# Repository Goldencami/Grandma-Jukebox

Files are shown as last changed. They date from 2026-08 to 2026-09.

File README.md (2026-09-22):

# Grandma-Jukebox
Jukebox to play songs for grandma.

The micro SD card (32GB) contains two folders named `canciones` and `himnos` in which their corresponding mp3 files are located.

> WARNING: Do **NOT** use GPIO19 or GPIO20 on this board. These GPIOs are internally connected to the USB-OTG and causes the USB no being detected by the computer. IF you accidentally upload a sketch and used those pins, you can upload an empty sketch using USB-UART and the communication with USB-OTG will work again.

> WARNING: Do NOT use GPIO2 for buttons or any other digital I/O. It is an ESP32-S3 strapping pin sampled at boot — depending on its state at power-on, it can prevent the board from booting correctly.

In development, use the USB-UART to upload code. The final version will use the charging cable to connect to USB-OTG.

https://github.com/user-attachments/assets/e78aba78-86dd-4827-824b-220895683b4c

## Commands
### Idle Screen (BMO Face)
- **Yellow Button**:  Go to the Music Type Selection screen.
- **Red Button**: Hold for 3 seconds to go to the Configuration screen.

### Music Type Selection Screen
*(selecting between "Canciones" and "Himnos Biblicos")*
- **White Button**: Toggles between the two playlist options.
- **Red Button**: Goes back to Idle Screen.
- **Green Button**: CONFIRMS — loads and plays the selected playlist, then goes to the Now Playing screen.

### Now Playing Screen
- **Green Button**: Plays/pauses the current song.
- **White Button**: Plays next song.
- **Yellow Button**: Plays previous song.
- **Red Button**: Stops the music and goes back to Idle Screen.

### Configuration Screen
*(setting date, then time — one field at a time: month → day → year, then hour → minute → AM/PM)*
- **White Button**: Increases the value of the currently selected field.
- **Yellow Button**: Decreases the value of the currently selected field.
- **Green Button**: Confirms the current field and moves to the next one. On the last field of date/time, it also saves the value and advances to the next step (date → time → back to Idle).
- **Red Button**: Cancels and goes back to Idle Screen.

## Components
- ESP32-S3 WROOM: Dual-core 32-bit microprocessor up to 240 MHz, 16 MB Flash, 16 MB PSRAM
- 3.2" 240x320 SPI TFT Display — ST7789 driver chip (confirmed; not ILI9341 despite some markings/assumptions — see Display Driver section below)
- DS3231 RTC
- MAX98357A I2S
- 3525 4ohm 3W-2.0port
- TF Micro SD Card Module with an onboard 3.3V voltage regulator circuit
- 32GB Sandisk Ultra Micro SD card
- 4 x push buttons

## Display Driver — IMPORTANT
This panel's actual controller is ST7789, not ILI9341. Use the `Adafruit_ST7789` library (via "Adafruit ST7735 and ST7789 Library" in Library Manager), not `TFT_eSPI` and not `Adafruit_ILI9341`.

**Why not TFT_eSPI**: `TFT_eSPI` crashes with a `Guru Meditation Error: StoreProhibited` (`EXCVADDR: 0x00000010`) immediately on `tft.init()`, on this exact hardware. This was confirmed reproducible across two different ESP32-S3 boards, multiple ESP32 Arduino core versions (3.2.x and 2.0.17), both ILI9341 and ST7789 driver settings, both RGB/BGR color order settings, and using the library's own unmodified stock example sketch. Root cause was never conclusively identified — suspected ESP-IDF 5.x SPI/DMA internals incompatibility — but it is reliably reproducible, so this library should be avoided for this project.

**Why not Adafruit_ILI9341**: Works partially (boots, draws, colors correctable via a manual R/B channel swap) but the addressable drawing window doesn't match the physical glass — roughly 1/5 of the right edge of the screen is not usable. This confirms the controller is not actually ILI9341.

**Use hardware SPI, not the simple constructor**: The plain `Adafruit_ST7789(CS, DC, MOSI, SCLK, RST)` constructor falls back to software SPI on ESP32, which is slow enough to make `loop()` unresponsive. Use the hardware-SPI constructor (an explicit `SPIClass` bound to a free SPI bus) instead, and call `setSPISpeed()` so the higher clock actually takes effect.

Confirmed working setup (`Adafruit_ST7789`):
```cpp
#include <Adafruit_ST7789.h>

SPIClass tftSPI(FSPI);
Adafruit_ST7789 tft = Adafruit_ST7789(&tftSPI, TFT_CS, TFT_DC, TFT_RST);

tftSPI.begin(TFT_SCLK, -1, TFT_MOSI, TFT_CS); // hardware SPI bus, no MISO needed
tft.init(240, 320);         // native resolution, required
tft.setSPISpeed(20000000);  // only takes effect with hardware SPI
tft.invertDisplay(false);   // REQUIRED — this panel needs inversion off;
                             // library defaults to inverted (ST77XX_INVON),
                             // which shows colors wrong (e.g. white as black)
tft.setRotation(1);         // landscape: width=320, height=240
```

If you ever swap in a genuinely different physical panel, re-verify the driver chip and re-test `invertDisplay(true)` vs `false` and color order before assuming this config still applies.

## Enable PSRAM in the IDE
This project enables PSRAM.

In Arduino IDE:
- Tools → PSRAM and set it to "OPI PSRAM"
- Tools → Flash Size: "16 MB (128Mb)".
- Tools → Partition Scheme: "16M Flash (2MB APP/12.5MB FATFS)".

> These are the PSRAM, Flash size and Partition Scheme values for the ESP32 that is being used.
>
> TODO: confirm and document *why* PSRAM is required (e.g. instability/crash without it) — the sketch doesn't call `ps_malloc`/`ps_calloc` directly, so if this was needed for a specific crash or buffer, note it here for future reference.

## Pinouts with ESP32


> TFT and the SD card are sharing the same SPI buses (MOSI, SCK)
### SPI TFT Screen
| SPI TFT | ESP32 |
|---|---|
| `VCC` | `3.3V` |
| `GND` | `GND` |
| `CS` | `GPIO15` |
| `RESET` | `GPIO8` |
| `DC` | `GPIO4` |
| `SDI (MOSI)` | `GPIO11` |
| `SCK` | `GPIO12` |
| `LED` | `3.3V` |

### SD CARD MODULE
| SD Card | ESP32 |
|---|---|
| `GND` | `GND` |
| `VCC` | `VIN` |
| `MISO` | `GPIO40` |
| `MOSI` | `GPIO41` |
| `SLK` | `GPIO39` |
| `CS` | `GPIO10` |

### DS3231 RTC
| DS3231 RTC | ESP32 |
|---|---|
| `GND` | `GND` |
| `VCC` | `VIN` |
| `SDA` | `GPIO21` |
| `SCL` | `GPIO47` |

### MAX98357 I2S
| MAX98357 I2S | ESP32 |
|---|---|
| `VIN` | `VIN` |
| `GND` | `GND` |
| `LRC` | `GPIO13` |
| `BCLK` | `GPIO14` |
| `DIN` | `GPIO9` |

### BUTTONS
| BUTTONS | ESP32 |
|---|---|
| `YELLOW` | `GPIO16` |
| `WHITE` | `GPIO17` |
| `RED` | `GPIO38` |
| `GREEN` | `GPIO1` |



## Credits
The arms and legs are from the [BMO model](https://www.printables.com/model/1582055-bmo-from-adventure-time-local-ai-agent-project) by brenpoly, licensed under [CC BY-NC 4.0](http://creativecommons.org/licenses/by-nc/4.0/). They were scaled to 1.5x to fit BMO's body. No other parts of that model were used.

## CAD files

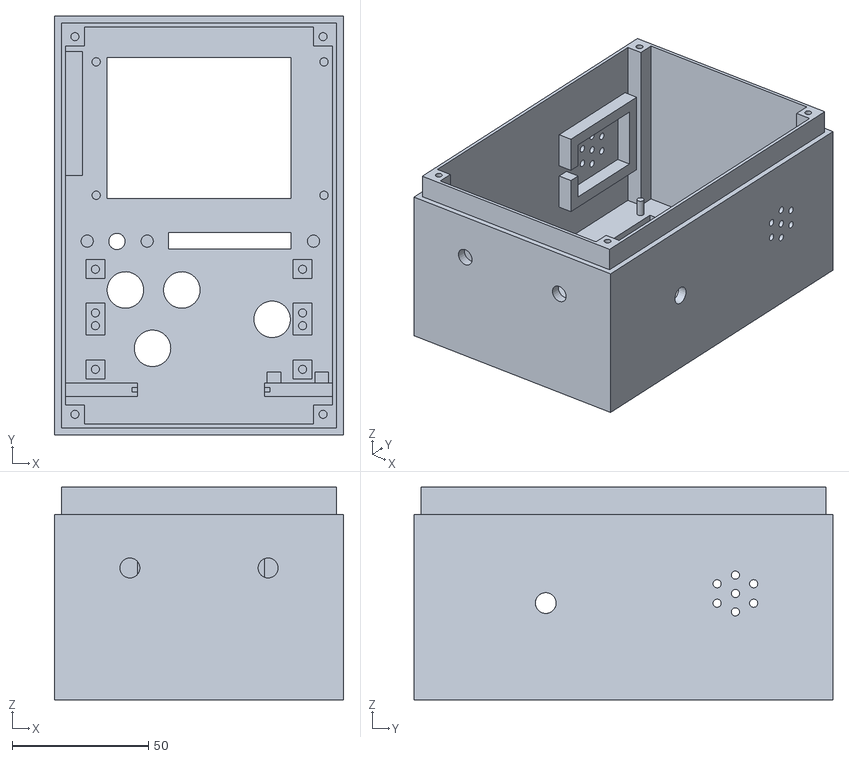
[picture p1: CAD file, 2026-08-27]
print_files/BMO_Front.stl
106.0 x 153.5 x 78.0

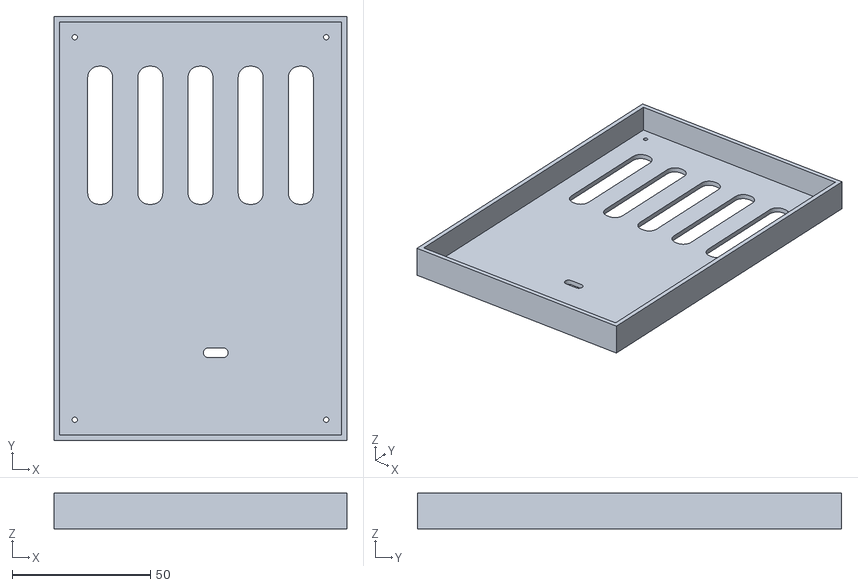
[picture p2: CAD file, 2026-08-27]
print_files/BMO_Back.stl
106.0 x 153.5 x 13.0

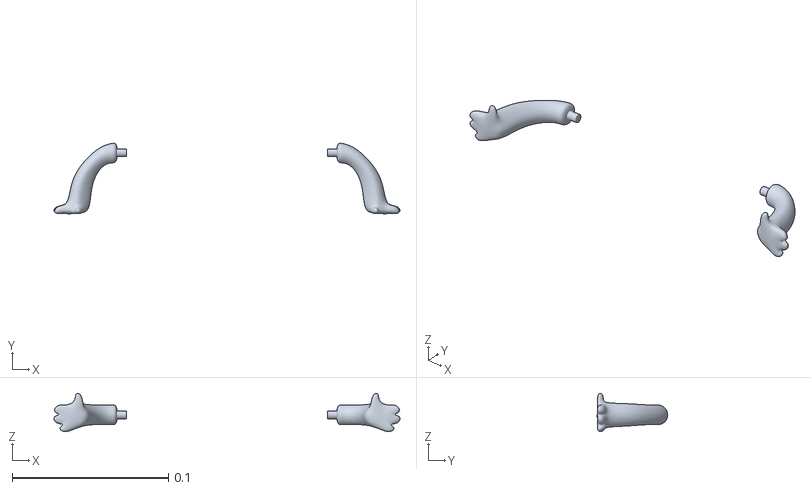
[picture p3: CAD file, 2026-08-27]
print_files/Arms_BMO.stl
0.221 x 0.0451 x 0.0245

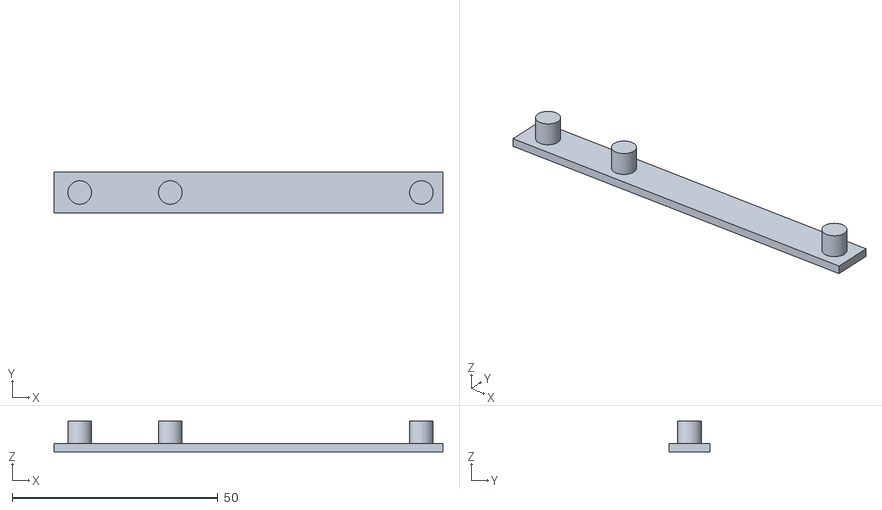
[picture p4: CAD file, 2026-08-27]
print_files/BMO_Disk.stl
94.5 x 10.0 x 7.50

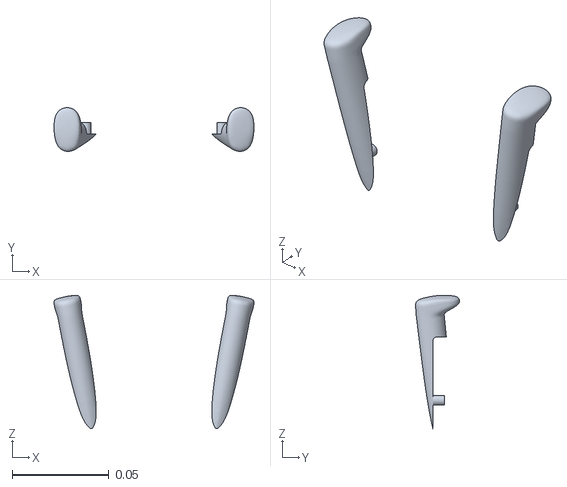
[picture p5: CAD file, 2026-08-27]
print_files/Legs_BMO.stl
0.103 x 0.0226 x 0.0689

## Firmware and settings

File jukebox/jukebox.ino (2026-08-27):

#include <SPI.h>
#include <SD.h>
#include <Adafruit_GFX.h>
#include <Adafruit_ST7789.h>
#include <Wire.h>
#include <RTClib.h>
#include <AudioFileSourceSD.h>
#include <AudioGeneratorMP3.h>
#include <AudioOutputI2S.h>
#include "esp_task_wdt.h"
#include "esp_log.h"
#include <Fonts/FreeSansBold12pt7b.h> 

#define YELLOW_BTN 16
#define WHITE_BTN 17
#define RED_BTN 38
#define GREEN_BTN 1

#define I2S_LRC  13
#define I2S_BCLK 14
#define I2S_DOUT 9

#define RTC_SDA 21
#define RTC_SCL 47

#define SD_SCK   39
#define SD_MISO  40
#define SD_MOSI  41
#define SD_CS    10

#define TFT_CS   15
#define TFT_DC    4
#define TFT_RST   8
#define TFT_MOSI 11
#define TFT_SCLK 12

// TIME VARIABLES
unsigned int debounceDelayYellow = 500;
unsigned long lastYellowDebounce = millis();
byte yellowBtnState = LOW;

unsigned int debounceDelayWhite = 500;
unsigned long lastWhiteDebounce = millis();
byte whiteBtnState = LOW;

unsigned int debounceDelayRed = 500;
unsigned long lastRedDebounce = millis();
byte redBtnState = LOW;

unsigned int debounceDelayGreen = 500;
unsigned long lastGreenDebounce = millis();
byte greenBtnState = LOW;

unsigned int RTCdelay = 500;
unsigned long lastRTCdelay = millis();

// MAX98357 I2S VARIABLES
String musicFiles[50];
int fileCount = 0;
int currentSong = 0;

// AUDIO OBJECTS (ESP8266Audio — runs on Core 0 via audioTask)
AudioGeneratorMP3 *mp3       = nullptr;
AudioFileSourceSD *audioSrc  = nullptr;
AudioOutputI2S    *audioOut  = nullptr;

// Shared state between loop() on Core 1 and audioTask on Core 0.
// Protected by audioMutex to avoid race conditions.
volatile bool audioShouldPlay = false;   // Core 1 sets true to start a song
volatile bool audioShouldStop = false;   // Core 1 sets true to stop mid-song
volatile bool audioIsPlaying  = false;   // Core 0 sets true while decoding
volatile bool audioPaused     = false;   // Core 1 toggles to pause/resume
volatile int  audioTrackIndex = 0;       // which track to play
SemaphoreHandle_t audioMutex;
TaskHandle_t audioTaskHandle = nullptr;
volatile bool manualStop = false;

// RTC VARIABLES
RTC_DS3231 rtc;
String previousTime = "-1";
String dateArr[3]; // [month, day, year]
String hoursArr[3]; // [hour, minute, AM/PM]
String tempDateArr[3];
String tempHourArr[3];
bool isSetDateDone = false;
bool isSetHourDone = false;

int lastDateIdx = -1;
int lastTimeIdx = -1;

// Convert month number to Spanish month name
const char* months[] = {"", "Enero", "Febrero", "Marzo", "Abril", "Mayo", "Junio", "Julio", "Agosto", "Septiembre", "Octubre", "Noviembre", "Diciembre"};
int monthIdx = 0;

// SD CARD VARIABLES
SPIClass sdSPI(HSPI);   // plain object, not a pointer - no TFT in this sketch to order against

// TFT VARIABLES —> using hardware SPI constructor so setSPISpeed() actually works.
// The simple Adafruit_ST7789(CS, DC, MOSI, SCLK, RST) constructor uses software
// SPI internally on ESP32, which is extremely slow and makes loop() unresponsive.
SPIClass tftSPI(FSPI);
Adafruit_ST7789 tft = Adafruit_ST7789(&tftSPI, TFT_CS, TFT_DC, TFT_RST);

// STATE MACHINE VARIABLES
enum State {
  IDLE,
  SELECTION,
  PLAY,
  CONFIGS
};

State state = IDLE;

bool isIdleScreenDisplayed = false;
bool isMusicTypeDisplayed = false;
bool isConfigScreenDisplayed = false;

// BMO FUNCTIONS
uint16_t bmoGreen;

void drawSmile(int cx, int cy, int r) {
  for (int a = 20; a <= 160; a++) {
    float rad = a * DEG_TO_RAD;

    int x = cx + r * cos(rad);
    int y = cy + r * sin(rad);

    tft.fillCircle(x, y, 2, ST77XX_BLACK);
  }
}

void BMOidleFace() {
  int w = tft.width();
  int h = tft.height();

  // background
  tft.fillScreen(bmoGreen);
  previousTime = "-1";   // force RTC to redraw on next tick — fillScreen wiped it

  // eye settings
  int eyeR = 7;
  int eyeY = h * 0.35;

  tft.fillCircle(w * 0.3, eyeY, eyeR, ST77XX_BLACK);
  tft.fillCircle(w * 0.7, eyeY, eyeR, ST77XX_BLACK);

  // smile :)
  drawSmile(w / 2, h * 0.43, 40);
}

void drawArrow(int width, int y) {
  int x = 20 + width + 5;

  tft.fillTriangle(
    x, y - 8,
    x + 10, y - 15,
    x + 10, y + 2,
    ST77XX_BLACK
  );
}

void eraseArrow(int width, int y) {
  int x = 20 + width + 5; 

  tft.fillTriangle(
    x, y - 8,
    x + 10, y - 15,
    x + 10, y + 2,
    bmoGreen
  );
}

void drawDownArrow(int width, int y) {
  int x = 20 + width + 5;

  tft.fillTriangle(
    x,      y - 10,  // top-left of base
    x + 10, y - 10,  // top-right of base
    x + 5,  y,       // bottom tip
    ST77XX_BLACK
  );
}

void eraseDownArrow(int width, int y) {
  int x = 20 + width + 5;

  tft.fillTriangle(
    x,      y - 10,  // top-left of base
    x + 10, y - 10,  // top-right of base
    x + 5,  y,       // bottom tip
    bmoGreen
  );
}

// Wraps `text` onto a second line if it's too wide to fit within `maxWidth`
// pixels (measured using the TFT's current font). Breaks at the last space
// that still fits on line 1. Returns 1 or 2 (the number of lines used).
int wrapTextTwoLines(const String &text, int maxWidth, String &line1, String &line2) {
  int16_t x1, y1;
  uint16_t w, h;

  tft.getTextBounds(text, 0, 0, &x1, &y1, &w, &h);
  if (w <= maxWidth) {
    line1 = text;
    line2 = "";
    return 1;
  }

  // Walk through spaces, keeping the furthest break point that still fits
  int breakIdx = -1;
  int searchFrom = 0;
  while (true) {
    int spaceIdx = text.indexOf(' ', searchFrom);
    if (spaceIdx == -1) break;

    tft.getTextBounds(text.substring(0, spaceIdx), 0, 0, &x1, &y1, &w, &h);
    if (w <= maxWidth) {
      breakIdx = spaceIdx;
      searchFrom = spaceIdx + 1;
    } else {
      break;
    }
  }

  if (breakIdx == -1) {
    // no single space makes line 1 fit (e.g. one very long word) —
    // just show it as one line rather than butchering a word.
    line1 = text;
    line2 = "";
    return 1;
  }

  line1 = text.substring(0, breakIdx);
  line2 = text.substring(breakIdx + 1);
  return 2;
}

void drawSong(String path) {
  int secondIndex = path.indexOf("/", path.indexOf("/") + 1);

  String songMP3 = path.substring(secondIndex + 1);
  String title = songMP3.substring(0, songMP3.length()-4);

  // convention title is: artistName - songName
  int dashIdx = title.indexOf("-");
  String artist = title.substring(0, dashIdx - 1);
  String song = title.substring(dashIdx + 2, title.length());

  tft.fillRect(0, 0, 320, 150, bmoGreen);
  tft.setTextColor(ST77XX_BLACK, bmoGreen);

  int16_t x1, y1;
  uint16_t w, h;

  // wrap  song title onto a second line if too wide for the screen
  const int maxTitleWidth = 300; // ~10px margin on each side
  const int lineHeight = 28;
  String songLine1, songLine2;
  int lineCount = wrapTextTwoLines(song, maxTitleWidth, songLine1, songLine2);

  int songStartY = (lineCount == 2) ? 55 : 70;

  tft.getTextBounds(songLine1, 0, 0, &x1, &y1, &w, &h);
  tft.setCursor((320 - w) / 2, songStartY);
  tft.print(songLine1);

  if (lineCount == 2) {
    tft.getTextBounds(songLine2, 0, 0, &x1, &y1, &w, &h);
    tft.setCursor((320 - w) / 2, songStartY + lineHeight);
    tft.print(songLine2);
  }

  // Center artist name below the song title, shifting down if it wrapped
  int artistY = songStartY + (lineCount - 1) * lineHeight + 45;
  tft.getTextBounds(artist, 0, 0, &x1, &y1, &w, &h);
  tft.setCursor((320 - w) / 2, artistY);
  tft.print(artist);
}

void displayConfigs() {
  tft.fillScreen(bmoGreen);
  tft.setCursor(20, 40);
  tft.print("Configuraciones");

  DateTime now = rtc.now();
  getDate(tempDateArr, now);
  getHour(tempHourArr, now);
}

// MUSIC FUNCTIONS
int musicIdx = 0;
void displayMusicTypes() {
  tft.fillScreen(bmoGreen);
  previousTime = "-1";   // force RTC to redraw on next tick — fillScreen wiped it

  tft.setTextColor(ST77XX_BLACK);

  tft.setCursor(20, 40);
  tft.print("Reproductor de musica");

  tft.setCursor(20, 90);
  tft.print("Canciones");

  tft.setCursor(20, 120);
  tft.print("Himnos Biblicos");
}

void selectMusic() {
  if (handleWhiteBtn()) {
    musicIdx = (musicIdx + 1) % 2;
    // erase both first
    eraseArrow(135, 90);
    eraseArrow(200, 120);
  }

  if (musicIdx == 0) {
    drawArrow(135, 90);
  }
  else  {
    drawArrow(200, 120);
  }
}

void playMusic(int index) {
  String path = musicFiles[index];

  // Signal Core 0 audio task to play this track.
  // drawSong() runs here on Core 1 — completely separate from audio decoding.
  xSemaphoreTake(audioMutex, portMAX_DELAY);
  audioTrackIndex  = index;
  audioShouldStop  = true; // stop any currently playing track first
  audioShouldPlay  = true; // then start the new one
  xSemaphoreGive(audioMutex);

  previousTime = "-1";   // force RTC to redraw after drawSong updates the screen
  drawSong(path);      // update screen immediately, doesn't wait for audio
}

void stopMusic() {
  xSemaphoreTake(audioMutex, portMAX_DELAY);
  audioShouldStop = true;
  audioShouldPlay = false;
  manualStop = true;
  xSemaphoreGive(audioMutex);
}

void pauseResumeMusic() {
  xSemaphoreTake(audioMutex, portMAX_DELAY);
  audioPaused = !audioPaused;
  xSemaphoreGive(audioMutex);
  // Serial.printf("Audio %s\n", audioPaused ? "paused" : "resumed");
}

// Called by audioTask on Core 0 when a track finishes naturally
void onTrackFinished() {
  currentSong++;
  if (currentSong >= fileCount) {
    currentSong = 0;
    state = IDLE;
  } else {
    playMusic(currentSong);
  }
}

void nextSong() {
  currentSong++;
  if (currentSong >= fileCount) {
    stopMusic();  // already sets manualStop = true
    currentSong = 0;
    state = IDLE;
  } 
  else {
    xSemaphoreTake(audioMutex, portMAX_DELAY);
    manualStop = true;  // ← add this before playMusic
    xSemaphoreGive(audioMutex);
    playMusic(currentSong);
  }
}

void previousSong() {
  if (currentSong <= 0) return;
  currentSong--;
  xSemaphoreTake(audioMutex, portMAX_DELAY);
  manualStop = true;
  xSemaphoreGive(audioMutex);
  playMusic(currentSong);
}

// Called automatically by the Audio library when a track finishes
void audio_eof_mp3(const char *info) {
  onTrackFinished();
}

// RTC FUNCTIONS
int dateIdx = 0;
void setDate(String *outputArray) {
  if (handleGreenBtn()) {
    if (dateIdx == 2) {
      int year = outputArray[2].toInt();
      int month = monthIdx;
      int day = outputArray[1].toInt();

      // safety clamps
      if (year < 2000) year = 2000;
      if (year > 2099) year = 2099;

      int maxDays = getMaxDays(month, year);
      if (day < 1) day = 1;
      if (day > maxDays) day = maxDays;

      DateTime now = rtc.now();
      rtc.adjust(DateTime(year, month, day, now.hour(), now.minute(), 0));

      dateArr[0] = outputArray[0];
      dateArr[1] = outputArray[1];
      dateArr[2] = outputArray[2];

      isSetDateDone = true;
      dateIdx = 0;

      tft.fillRect(20, 80, 250, 120, bmoGreen);
      return;
    }

    dateIdx++;
  }

  selectDate();

  if (handleWhiteBtn()) {
    tft.fillRect(20, 80, 250, 120, bmoGreen);

    if (dateIdx == 0) {
      monthIdx++;
      if (monthIdx > 12) monthIdx = 1;
      outputArray[0] = months[monthIdx];
    }
    else if (dateIdx == 1) {
      int year = outputArray[2].toInt();
      int tempDay = outputArray[1].toInt();

      tempDay++;
      int maxDays = getMaxDays(monthIdx, year);
      if (tempDay > maxDays) tempDay = 1;

      outputArray[1] = (tempDay < 10) ? "0" + String(tempDay) : String(tempDay);
    }
    else if (dateIdx == 2) {
      int tempYear = outputArray[2].toInt();
      tempYear++;
      if (tempYear > 2099) tempYear = 2000;
      outputArray[2] = String(tempYear);
    }
  }

  else if (handleYellowBtn()) {
    tft.fillRect(20, 80, 250, 120, bmoGreen);

    if (dateIdx == 0) {
      monthIdx--;
      if (monthIdx < 1) monthIdx = 12;
      outputArray[0] = months[monthIdx];
    }
    else if (dateIdx == 1) {
      int year = outputArray[2].toInt();
      int tempDay = outputArray[1].toInt();

      tempDay--;
      int maxDays = getMaxDays(monthIdx, year);
      if (tempDay < 1) tempDay = maxDays;

      outputArray[1] = (tempDay < 10) ? "0" + String(tempDay) : String(tempDay);
    }
    else if (dateIdx == 2) {
      int tempYear = outputArray[2].toInt();
      tempYear--;
      if (tempYear < 2000) tempYear = 2099;
      outputArray[2] = String(tempYear);
    }
  }

  String month = outputArray[0];

  int regionX = 40;
  int regionW = 100;
  int16_t x1, y1;
  uint16_t w, h;

  tft.getTextBounds(month, 0, 0, &x1, &y1, &w, &h);
  int textW = w;
  int x = regionX + (regionW - textW) / 2;

  tft.setCursor(x, 120);
  tft.print(month);

  tft.setCursor(170, 120);
  tft.print(outputArray[1]);

  tft.setCursor(210, 120);
  tft.print(outputArray[2]);
}

int getMaxDays(int month, int year) {
  if(month == 2) {
    bool leap = (year % 4 == 0 && year % 100 != 0) || (year % 400 == 0);
    return leap ? 29 : 28;
  }

  if(month == 4 || month == 6 || month == 9 || month == 11)
    return 30;

  return 31;
}

void selectDate() {
  if(dateIdx == 0) {
    eraseDownArrow(208, 90);
    drawDownArrow(60, 90);
  }
  else if(dateIdx == 1) {
    eraseDownArrow(60, 90);
    drawDownArrow(153, 90);
  }
  else if(dateIdx == 2) {
    eraseDownArrow(153, 90);
    drawDownArrow(208, 90);
  }
}

int timeIdx = 0;
void setHour(String *outputArray) {
  if (handleGreenBtn()) {
    if (timeIdx == 2) {
      int hour12 = outputArray[0].toInt();
      int minute = outputArray[1].toInt();
      String ampm = outputArray[2];

      if (minute < 0 || minute > 59) minute = 0;

      int hour24 = hour12;

      if (ampm == "PM" && hour12 != 12) hour24 += 12;
      if (ampm == "AM" && hour12 == 12) hour24 = 0;

      DateTime now = rtc.now();
      rtc.adjust(DateTime(now.year(), now.month(), now.day(), hour24, minute, 0));

      hoursArr[0] = outputArray[0];
      hoursArr[1] = outputArray[1];
      hoursArr[2] = outputArray[2];

      isSetHourDone = true;
      timeIdx = 0;

      tft.fillRect(20, 80, 250, 120, bmoGreen);
      return;
    }

    timeIdx++;
  }

  selectHour();

  if (handleWhiteBtn()) {
    tft.fillRect(20, 80, 250, 120, bmoGreen);

    if (timeIdx == 0) {
      int tempHour = outputArray[0].toInt();
      tempHour = (tempHour % 12) + 1;
      outputArray[0] = (tempHour < 10) ? "0" + String(tempHour) : String(tempHour);
    }
    else if (timeIdx == 1) {
      int tempMin = outputArray[1].toInt();
      tempMin = (tempMin + 1) % 60;
      outputArray[1] = (tempMin < 10) ? "0" + String(tempMin) : String(tempMin);
    }
    else if (timeIdx == 2) {
      outputArray[2] = (outputArray[2] == "AM") ? "PM" : "AM";
    }
  }

  else if (handleYellowBtn()) {
    tft.fillRect(20, 80, 250, 120, bmoGreen);

    if (timeIdx == 0) {
      int tempHour = outputArray[0].toInt();
      tempHour--;
      if (tempHour <= 0) tempHour = 12;

      outputArray[0] = (tempHour < 10) ? "0" + String(tempHour) : String(tempHour);
    }
    else if (timeIdx == 1) {
      int tempMin = outputArray[1].toInt();
      tempMin--;
      if (tempMin < 0) tempMin = 59;

      outputArray[1] = (tempMin < 10) ? "0" + String(tempMin) : String(tempMin);
    }
    else if (timeIdx == 2) {
      outputArray[2] = (outputArray[2] == "AM") ? "PM" : "AM";
    }
  }

  tft.setCursor(110, 120);
  tft.print(outputArray[0] + " : " + outputArray[1] + " " + outputArray[2]);
}

void selectHour() {
  if(timeIdx == 0) {
    eraseDownArrow(175, 90);
    drawDownArrow(93, 90);
  }
  else if(timeIdx == 1) {
    eraseDownArrow(93, 90);
    drawDownArrow(139, 90);
  }
  else if(timeIdx == 2) {
    eraseDownArrow(139, 90);
    drawDownArrow(175, 90);
  }
}

void getDate(String *outputArray, DateTime now) {
  String yearStr = String(now.year());
  String dayStr = (now.day() < 10 ? "0" : "") + String(now.day());
  String monthStr = (now.month() < 10 ? "0" : "") + String(now.month());
  monthIdx = now.month();
  monthStr = months[monthIdx];

  // [month, day, year]
  outputArray[0] = monthStr;
  outputArray[1] = dayStr;
  outputArray[2] = yearStr;
}

void getHour(String *outputArray, DateTime now) {
  // 12-hour clock
  int hour24 = now.hour();
  int hour12 = hour24 % 12;

  if (hour12 == 0) {
    hour12 = 12;
  }

  // [hour, minute, AM/PM]
  outputArray[0] = (hour12 < 10 ? "0" : "") + String(hour12);
  outputArray[1] = (now.minute() < 10 ? "0" : "") + String(now.minute());
  outputArray[2] = (hour24 < 12) ? "AM" : "PM";
}

void displayRTC() {
  DateTime now = rtc.now();
  getDate(dateArr, now);
  getHour(hoursArr, now);
  String formattedTime = dateArr[0] + " " + dateArr[1] + ", " + dateArr[2] + " - " + hoursArr[0] + ":" + hoursArr[1] + " " + hoursArr[2];

  if (formattedTime != previousTime) {
    tft.fillRect(0, 200, 320, 40, bmoGreen);
    tft.setTextColor(ST77XX_BLACK, bmoGreen);

    // measure to center text
    int16_t x1, y1;
    uint16_t w, h;
    tft.getTextBounds(formattedTime, 0, 0, &x1, &y1, &w, &h);
    int centeredX = (320 - w) / 2;

    tft.setCursor(centeredX, 220);
    tft.print(formattedTime); 

    previousTime = formattedTime;
  }
}

// BUTTON FUNCTIONS
bool handleYellowBtn() {
  unsigned long timeNow = millis();

  if(timeNow - lastYellowDebounce > debounceDelayYellow) {
    byte newBtnState = digitalRead(YELLOW_BTN);

    if(newBtnState != yellowBtnState) {
      yellowBtnState = newBtnState;
      lastYellowDebounce = timeNow;

      // because of pullups
      // pressed = LOW
      // released = HIGH
      if(yellowBtnState == LOW) {
        return true;
      }
    }
  }

  return false;
}

bool handleWhiteBtn() {
  unsigned long timeNow = millis();

  if(timeNow - lastWhiteDebounce > debounceDelayWhite) {
    byte newBtnState = digitalRead(WHITE_BTN);

    if(newBtnState != whiteBtnState) {
      whiteBtnState = newBtnState;
      lastWhiteDebounce = timeNow;

      // because of pullups
      // pressed = LOW
      // released = HIGH
      if(whiteBtnState == LOW) {
        return true;
      }
    }
  }

  return false;
}

bool handleRedBtn() {
  unsigned long timeNow = millis();

  if(timeNow - lastRedDebounce > debounceDelayRed) {
    byte newBtnState = digitalRead(RED_BTN);

    if(newBtnState != redBtnState) {
      redBtnState = newBtnState;
      lastRedDebounce = timeNow;

      // because of pullups
      // pressed = LOW
      // released = HIGH
      if(redBtnState == LOW) {
        return true;
      }
    }
  }

  return false;
}

bool handleGreenBtn() {
  unsigned long timeNow = millis();

  if(timeNow - lastGreenDebounce > debounceDelayGreen) {
    byte newBtnState = digitalRead(GREEN_BTN);

    if(newBtnState != greenBtnState) {
      greenBtnState = newBtnState;
      lastGreenDebounce = timeNow;

      // because of pullups
      // pressed = LOW
      // released = HIGH
      if(greenBtnState == LOW) {
        return true;
      }
    }
  }

  return false;
}

// Helper —> call only from Core 0 (audioTask)
void rampGain(float from, float to, int steps = 20, int stepMs = 5) {
  for (int i = 0; i <= steps; i++) {
    float g = from + (to - from) * i / steps;
    audioOut->SetGain(g);
    vTaskDelay(pdMS_TO_TICKS(stepMs));
  }
}
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
void loop() {
  static unsigned long redHoldStart = 0;

  if (digitalRead(RED_BTN) == LOW) {
    if (redHoldStart == 0) redHoldStart = millis();

    if (millis() - redHoldStart > 3000) {
      isSetDateDone = false;
      isSetHourDone = false;
      state = CONFIGS;
    }
  } else {
    redHoldStart = 0;
  }

  unsigned long timeNow = millis();
  if((timeNow - lastRTCdelay > RTCdelay) && state != CONFIGS) {
    lastRTCdelay = timeNow;
    displayRTC();
  }

  if(state == IDLE) {
    if(!isIdleScreenDisplayed) {
      BMOidleFace(); // also resets previousTime so RTC redraws immediately
      isIdleScreenDisplayed = true;
    }

    if(handleYellowBtn()) {
      state = SELECTION;
    }
  }
  else if(state == SELECTION) {
    isIdleScreenDisplayed = false;

    if(!isMusicTypeDisplayed) {
      displayMusicTypes();
      isMusicTypeDisplayed = true;
    }

    selectMusic();

    if(handleRedBtn()) {
      musicIdx = 0;
      isMusicTypeDisplayed = false;
      state = IDLE;
    }

    // GREEN confirms selection — load the chosen folder and start playing
    if(handleGreenBtn()) {
      String folder = (musicIdx == 0) ? "/canciones" : "/himnos";
      loadMusicFiles(folder);

      if(fileCount > 0) {
        currentSong = 0;
        isMusicTypeDisplayed = false;
        state = PLAY;
        playMusic(currentSong);   // drawSong() runs here on Core 1. Actual MP3 decode runs on Core 0
        lastGreenDebounce = millis();
      } else {
        Serial.println("No MP3 files found in folder");
      }
    }
  }
  else if(state == PLAY) {
    isIdleScreenDisplayed = false;
    
    // Button handling during playback
    if(handleGreenBtn()) pauseResumeMusic(); // PLAY/PAUSE toggle
    if(handleWhiteBtn()) nextSong();
    if(handleYellowBtn()) previousSong();

    if(handleRedBtn()) {
      stopMusic();
      musicIdx = 0;
      isMusicTypeDisplayed = false;
      state = IDLE;
    }
  }
  else if(state == CONFIGS) {
    isIdleScreenDisplayed = false;

    if(!isConfigScreenDisplayed) {
      displayConfigs();
      isConfigScreenDisplayed = true;
    }

    if(handleRedBtn()) {
      dateIdx = 0;
      timeIdx = 0;
      lastDateIdx = -1;
      lastTimeIdx = -1;

      isSetDateDone = false;
      isSetHourDone = false;
      isConfigScreenDisplayed = false;

      state = IDLE;
    }


    if(!isSetDateDone && !isSetHourDone) {
      setDate(tempDateArr);
    }
    else if(isSetDateDone && !isSetHourDone) {
      setHour(tempHourArr);
    }

    if(isSetDateDone && isSetHourDone) {
      isSetDateDone = false;
      isSetHourDone = false;

      dateIdx = 0;
      timeIdx = 0;
      lastDateIdx = -1;
      lastTimeIdx = -1;

      isConfigScreenDisplayed = false;
      state = IDLE;
    }
  }
}

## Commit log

2026-05-31 fixed smile width and height
    [jukebox.ino]
2026-05-31 setup buttons and solved debounce issue
    [jukebox.ino]
2026-06-01 changed buttons pins
2026-06-01 configured SD card and changes button pins
2026-06-02 shared SPI between sd card and tft
2026-06-02 Update README with materials and pinouts
    Added materials and pinout details for the ESP32 project.
2026-06-05 created functions to play audio (not tested)
    couldnt test audio due to not having the correct microcontroller for the moment
    [jukebox.ino]
2026-06-06 updated configs and made code better
    not tested, need to wait for the new esp32 S3
2026-06-14 fixed GPIO and SD card freezing when opening
    [jukebox.ino]
2026-06-15 fixed SPI sharing between SD and TFT
    [jukebox.ino]
2026-06-15 Update README with PSRAM configuration instructions
    Added instructions for enabling PSRAM in the Arduino IDE.
2026-06-15 fixed RTC display delay and name of song gets displayed on screen
    [jukebox.ino]
2026-06-16 Update README with pinout image and SPI details
    Added image for pinouts and clarified SPI bus usage.
2026-06-16 Simplify materials list in README
2026-06-22 fixed code to work on core 0 and core 1 for UI and Audio
    [jukebox.ino]
2026-06-22 fixed audio pause, removed noise
    [jukebox.ino]
2026-06-22 fixed screen slide when it changes
    [jukebox.ino]
2026-06-22 stopped buzz sound when selecting song type
    [jukebox.ino]
2026-06-22 fixed buzz sounf when executing previousSong function
    [jukebox.ino]
2026-08-27 added the 3d models to print
    [Arms_BMO.stl, BMO_Back.stl, BMO_Disk.stl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]
2026-08-27 fixed singer last letter gets cut off
    [jukebox.ino]
2026-09-02 Update README with user attachments link
    Add link to user attachments in README
